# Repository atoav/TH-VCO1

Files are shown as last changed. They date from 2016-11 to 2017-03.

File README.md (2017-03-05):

# TH-VCO1

This is a fork based on [the Eurorack Layout Tom Whitwell]( http://www.birthofasynth.com/Thomas_Henry/Pages/VCO-1.html) Oscillator published for the [Thomas Henry VCO 1](http://www.birthofasynth.com/Thomas_Henry/Pages/VCO-1.html) Oscillator.

**NB: All rights to this design rest with Thomas Henry. I do not claim or grant any copyright or license to this design. This is the outcome of an University course at HFBK Hamburg. A limited run of 100 pieces has been produced, which will be sold. We are not allowed to share CAD files of the circuit as "Thomas Henry prefers that all hardware for my designs come from Fonik only, and that schematics for his designs come from Scott and E-M". I will take this page down if he asks me to.** 

## Changes
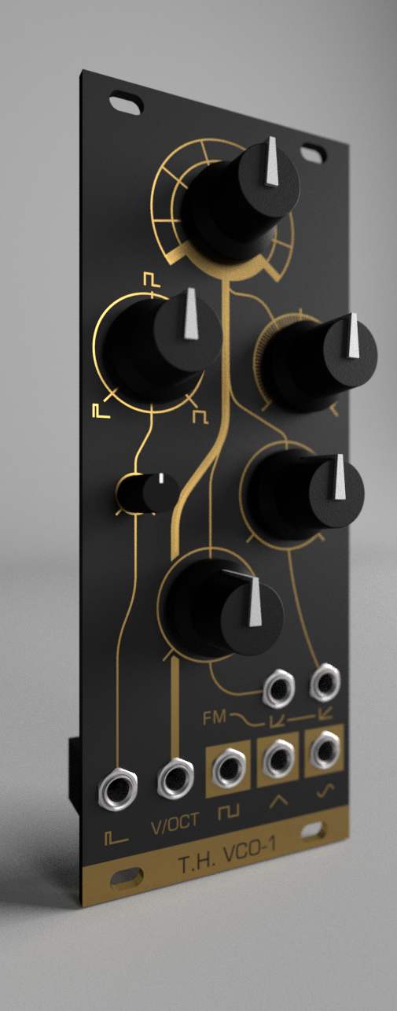
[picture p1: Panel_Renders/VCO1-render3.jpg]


Compared to Tom's Layout some things changed:

- the complete panel layout has been changed for a fancier (and imho a bit more easier to grasp) layout
- The board-pot has been completely rerouted and is now a single layer board (the bottom layer is a nice, undivided ground plane)
- Two 1x5 Header Pin Strips have been added (this could potentially help to save the screws and add mechanical stability)
- All Resistor Pads have been swapped for square pads
- The PWM CV Attenuator Pot is now a 9mm Alpha trimmer (the small ones with the plastic head, commonly used for attenuverters)
- Cleaned up traces and silkscreen where necessary

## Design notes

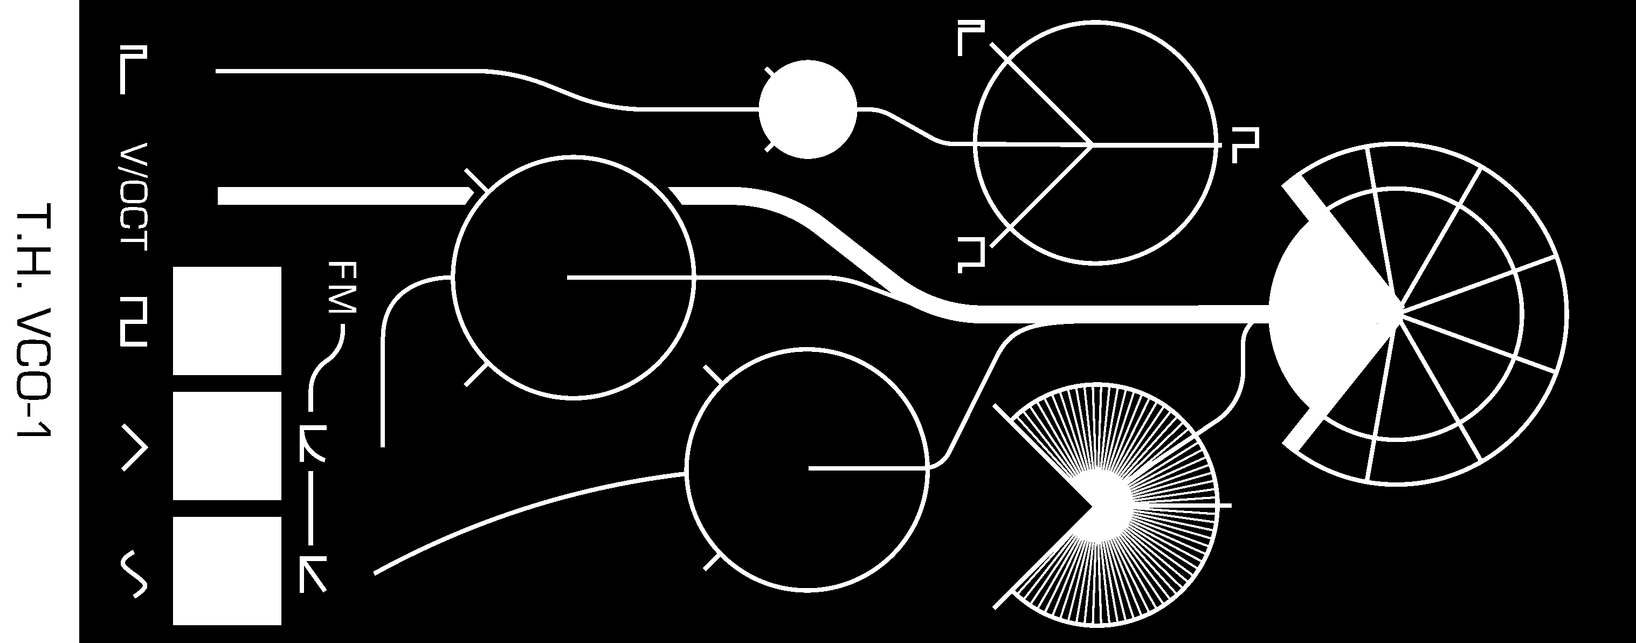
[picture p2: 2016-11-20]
Panel_Images/VCO1-Panel_Board-01.bmp

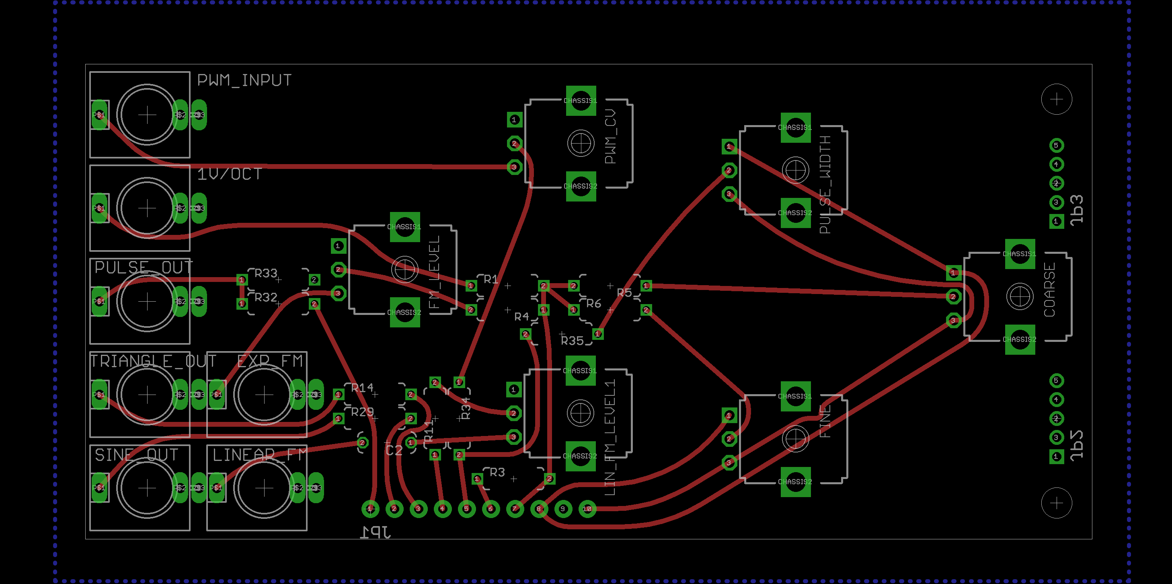
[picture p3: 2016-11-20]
Board_Images/vco1-board-pots.png

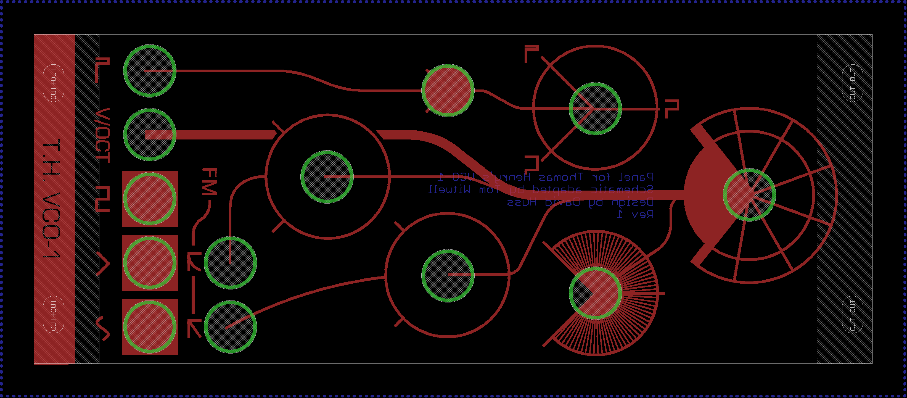
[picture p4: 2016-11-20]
Board_Images/vco1-board-panel.png

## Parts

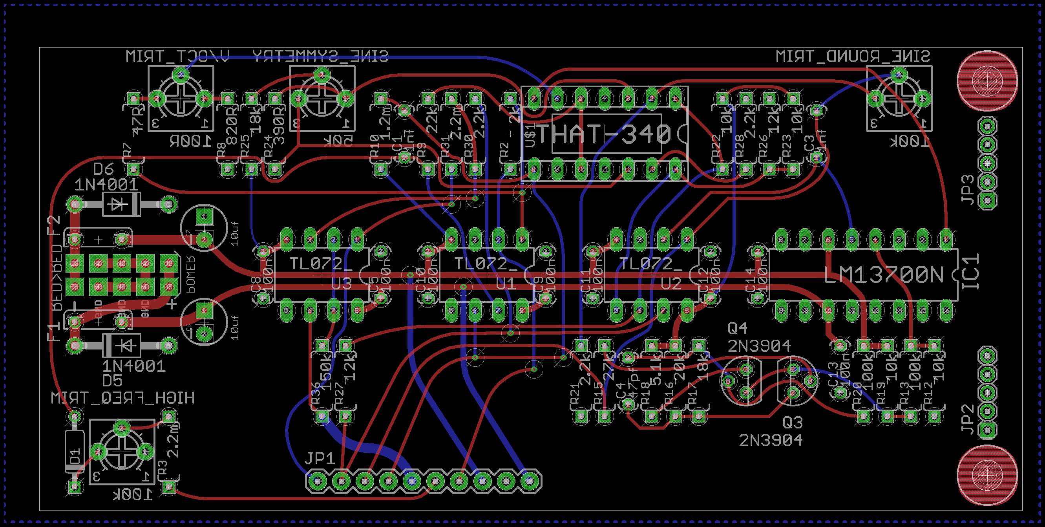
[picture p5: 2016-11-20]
Board_Images/vco1-board-components.jpg

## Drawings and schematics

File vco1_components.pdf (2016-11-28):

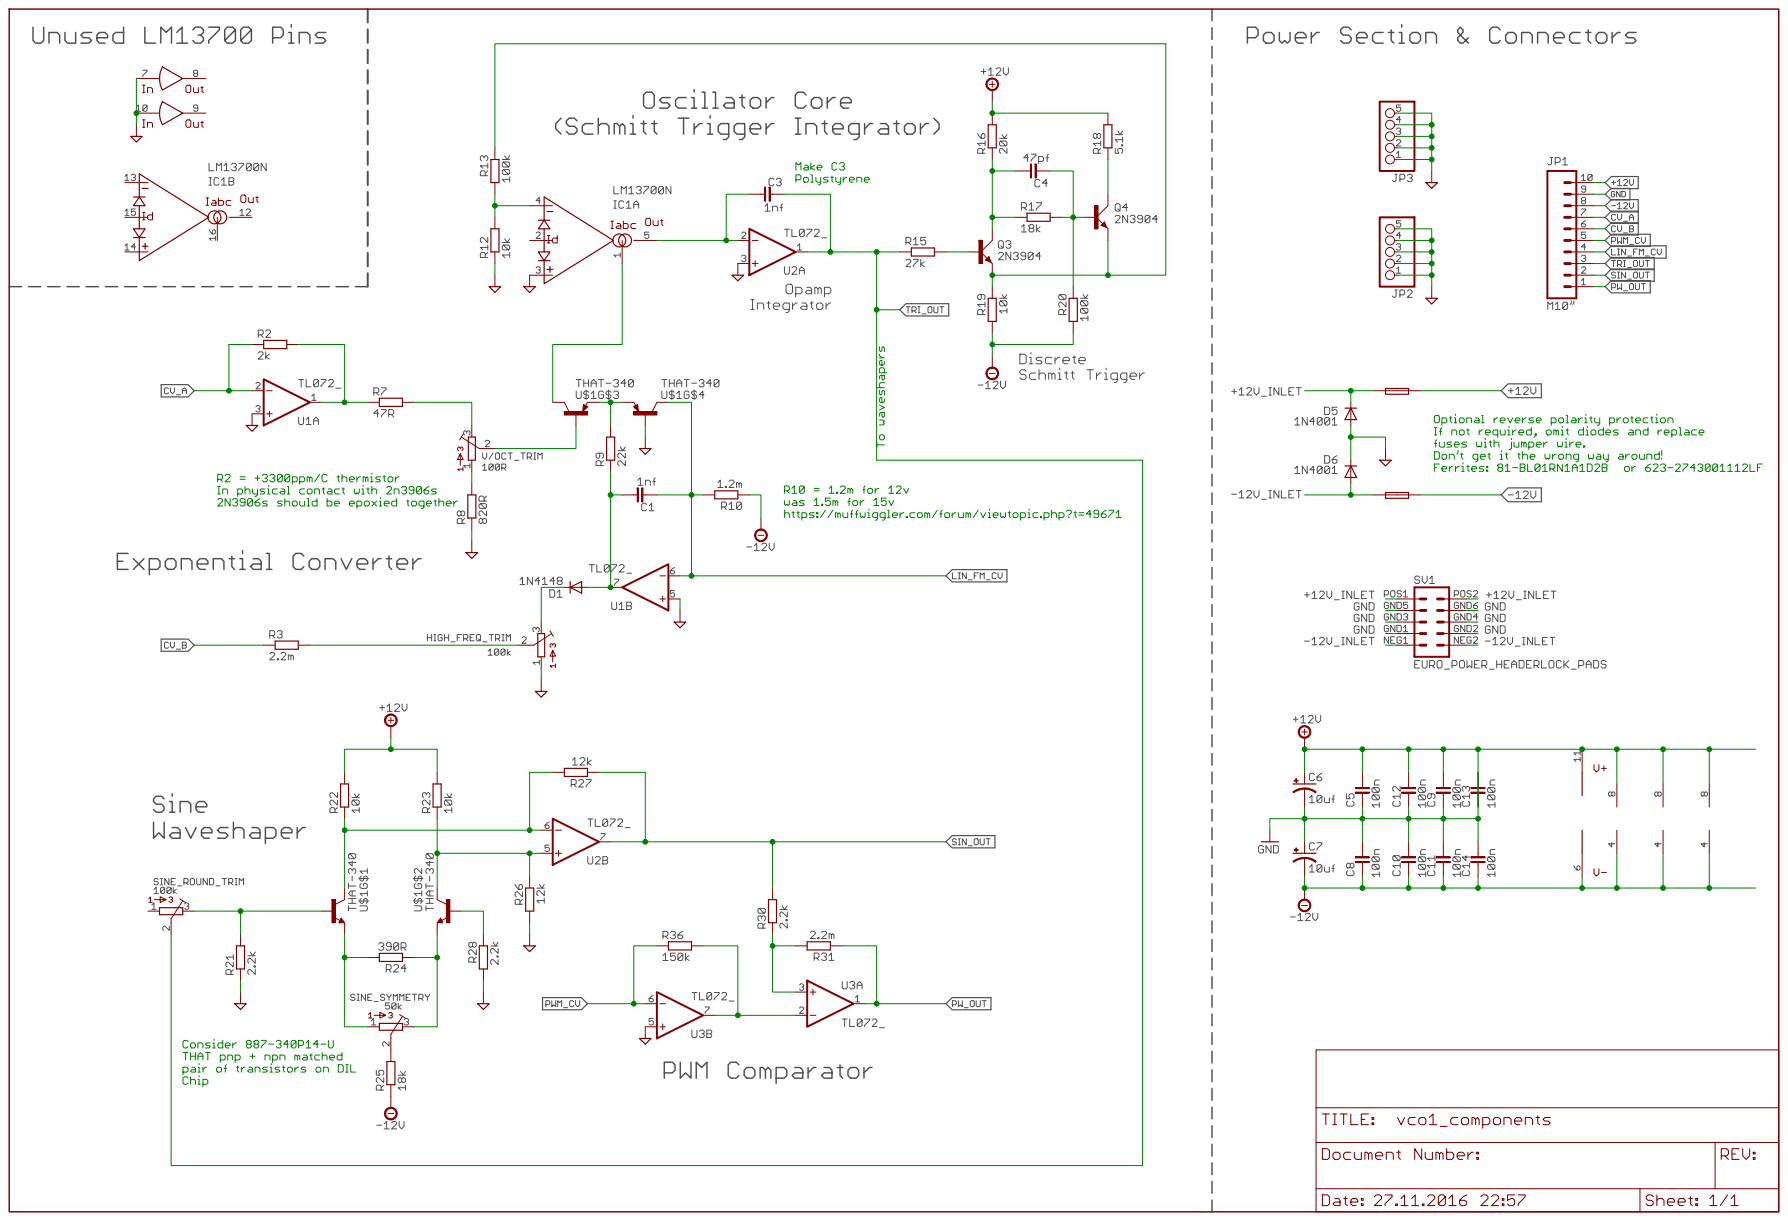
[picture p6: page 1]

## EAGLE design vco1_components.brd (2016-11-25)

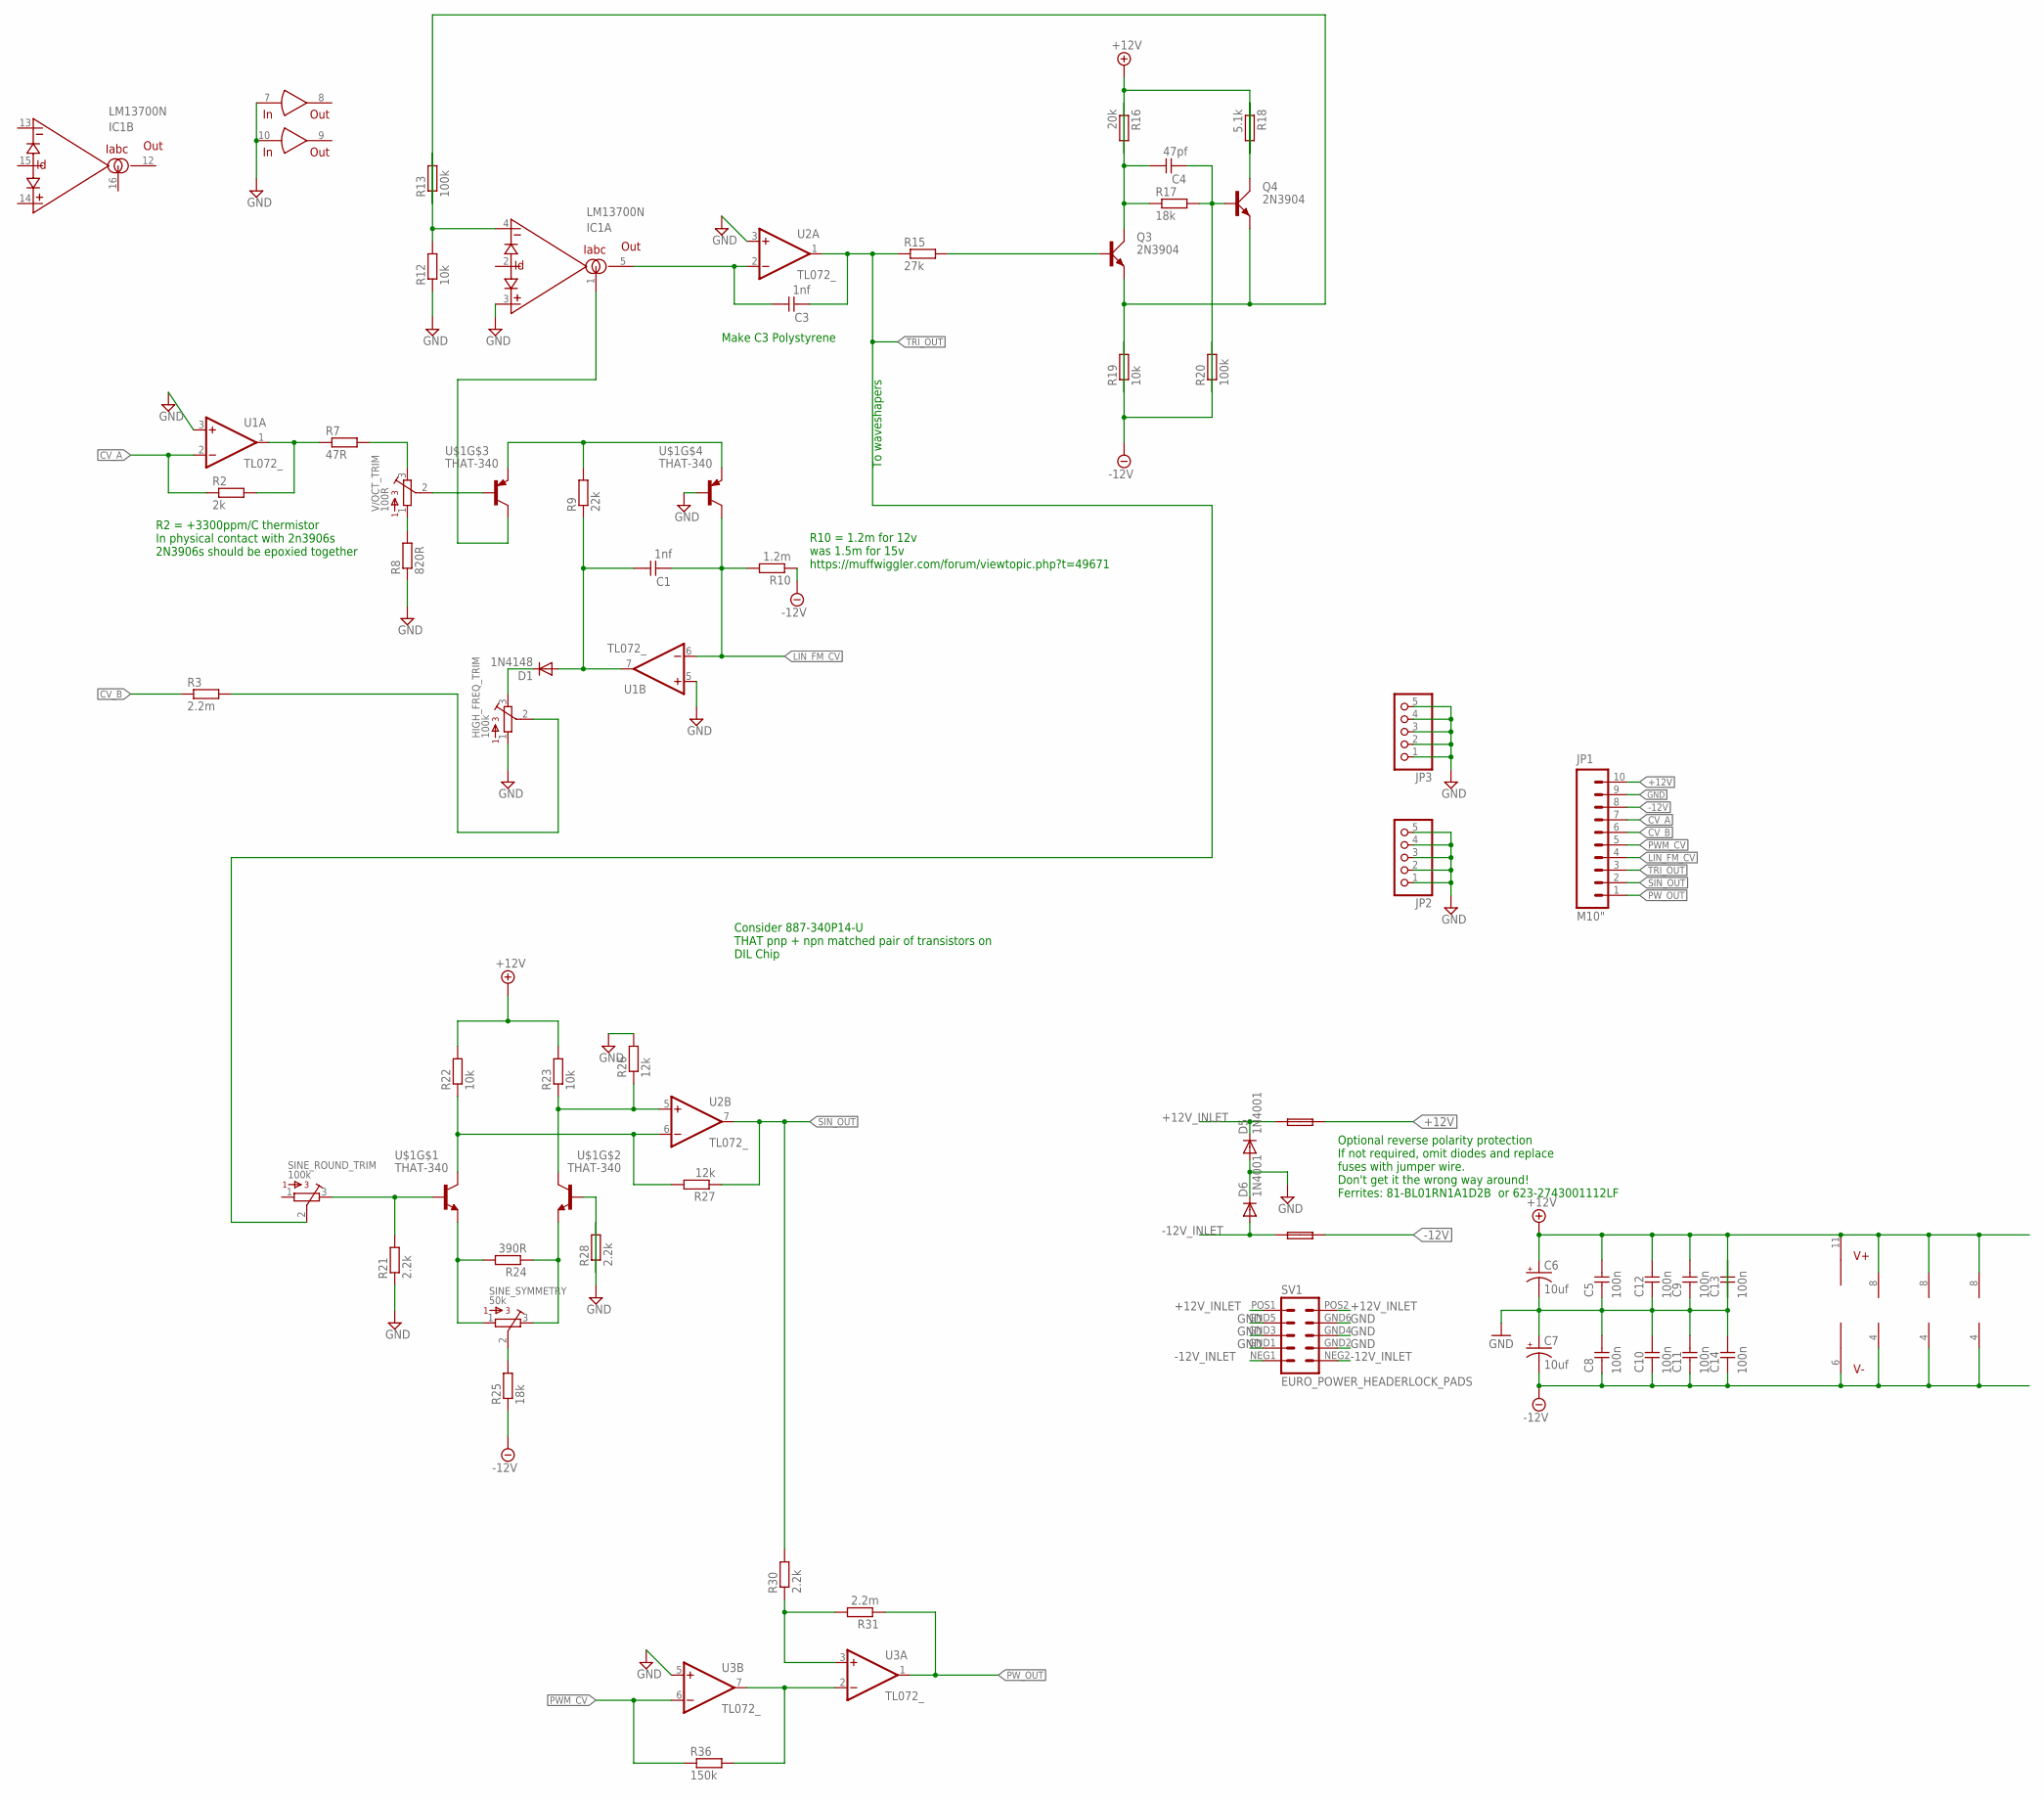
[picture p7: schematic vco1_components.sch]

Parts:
C1, C3: 1nf; C050-024X044
C4: 47pf; C050-024X044
C5, C8, C9, C10, C11, C12, C13, C14: 100n; C050-024X044
C6, C7: 10uf; CPOL-RADIAL-10UF-25V
D1: 1N4148; DO35-7
D5, D6: 1N4001; DO41-10
F1, F2: FUSE; C050H075X075
HIGH_FREQ_TRIM: 100k; BOURNS_3362P_TRIMMER
IC1: LM13700N; DIL16
JP1: M10"; 1X10
JP2, JP3: PINHD-1X55X2MM; 1_05X2MM
Q3, Q4: 2N3904; TO92D
R2: 2k; 7MM_RESISTOR
R3, R31: 2.2m; 7MM_RESISTOR
R7: 47R; 7MM_RESISTOR
R8: 820R; 7MM_RESISTOR
R9: 22k; 7MM_RESISTOR
R10: 1.2m; 7MM_RESISTOR
R12, R19, R22, R23: 10k; 7MM_RESISTOR
R13, R20: 100k; 7MM_RESISTOR
R15: 27k; 7MM_RESISTOR
R16: 20k; 7MM_RESISTOR
R17, R25: 18k; 7MM_RESISTOR
R18: 5.1k; 7MM_RESISTOR
R21, R28, R30: 2.2k; 7MM_RESISTOR
R24: 390R; 7MM_RESISTOR
R26, R27: 12k; 7MM_RESISTOR
R36: 150k; 7MM_RESISTOR
SINE_ROUND_TRIM: 100k; BOURNS_3362P_TRIMMER
SINE_SYMMETRY: 50k; BOURNS_3362P_TRIMMER
SV1: EURO_POWER_HEADERLOCK_PADS; EURO_PWR_HEADER_LOCK
U1, U2, U3: TL072_; DIL08
U$1: THAT-340; DIL14
V/OCT_TRIM: 100R; BOURNS_3362P_TRIMMER

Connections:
+12V: C5.1, C6.1 (+), C9.1, C12.1, C13.2, F1.2, IC1.11 (V+), JP1.10, R16.2, R18.2, R22.2, R23.2, U1.8 (V+), U2.8 (V+), U3.8 (V+)
+12V_INLET: D5.C, F1.1, SV1.POS1 (10), SV1.POS2 (9)
-12V: C7.2 (-), C8.2, C10.2, C11.2, C14.2, F2.2, IC1.6 (V-), JP1.8, R10.1, R19.2, R20.2, R25.1, U1.4 (V-), U2.4 (V-), U3.4 (V-)
-12V_INLET: D6.A, F2.1, SV1.NEG1 (2), SV1.NEG2 (1)
CV_A: JP1.7, R2.1, U1.2 (-IN)
CV_B: JP1.6, R3.1
GND: C5.2, C6.2 (-), C7.1 (+), C8.1, C9.2, C10.1, C11.1, C12.2, C13.1, C14.1, D5.A, D6.C, HIGH_FREQ_TRIM.1, IC1.3 (+IN), IC1.7 (IN), IC1.10 (IN), JP1.9, JP2.1, JP2.2, JP2.3, JP2.4, JP2.5, JP3.1, JP3.2, JP3.3, JP3.4, JP3.5, R8.1, R12.1, R21.1, R26.2, R28.2, SV1.GND1 (4), SV1.GND2 (3), SV1.GND3 (6), SV1.GND4 (5), SV1.GND5 (8), SV1.GND6 (7), U1.3 (+IN), U1.5 (+IN), U2.3 (+IN), U3.5 (+IN), U$1.9 (B)
LIN_FM_CV: C1.2, JP1.4, R10.2, U1.6 (-IN), U$1.8 (C)
unnamed: R2.2, R7.1, U1.1 (OUT)
unnamed: R7.2, V/OCT_TRIM.3
unnamed: R8.2, V/OCT_TRIM.1
unnamed: U$1.6 (B), V/OCT_TRIM.2
unnamed: R9.2, U$1.5 (E), U$1.10 (E)
unnamed: IC1.1 (IABC), U$1.7 (C)
unnamed: C1.1, D1.A, R9.1, U1.7 (OUT)
unnamed: D1.C, HIGH_FREQ_TRIM.3
unnamed: HIGH_FREQ_TRIM.2, R3.2
unnamed: IC1.4 (-IN), R12.2, R13.2
unnamed: C3.1, IC1.5 (OUT), U2.2 (-IN)
unnamed: Q3.B, R15.2
unnamed: C4.1, Q3.C, R16.1, R17.1
unnamed: R21.2, SINE_ROUND_TRIM.3, U$1.2 (B)
unnamed: C4.2, Q4.B, R17.2, R20.1
unnamed: Q4.C, R18.1
unnamed: R25.2, SINE_SYMMETRY.2
unnamed: Q3.E, Q4.E, R13.1, R19.1
unnamed: R22.1, R27.2, U2.6 (-IN), U$1.1 (C)
unnamed: R23.1, R26.1, U2.5 (+IN), U$1.14 (C)
unnamed: R24.2, SINE_SYMMETRY.1, U$1.3 (E)
unnamed: R24.1, SINE_SYMMETRY.3, U$1.12 (E)
unnamed: R28.1, U$1.13 (B)
unnamed: R30.1, R31.2, U3.3 (+IN)
unnamed: R36.2, U3.2 (-IN), U3.7 (OUT)
PWM_CV: JP1.5, R36.1, U3.6 (-IN)
PW_OUT: JP1.1, R31.1, U3.1 (OUT)
SIN_OUT: JP1.2, R27.1, R30.2, U2.7 (OUT)
TRI_OUT: C3.2, JP1.3, R15.1, SINE_ROUND_TRIM.2, U2.1 (OUT)

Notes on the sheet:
To waveshapers
R2 = +3300ppm/C thermistor In physical contact with 2n3906s 2N3906s should be epoxied together
Make C3 Polystyrene
R10 = 1.2m for 12v was 1.5m for 15v https://muffwiggler.com/forum/viewtopic.php?t=49671
Consider 887-340P14-U THAT pnp + npn matched pair of transistors on DIL Chip
Optional reverse polarity protection If not required, omit diodes and replace fuses with jumper wire. Don't get it the wrong way around! Ferrites: 81-BL01RN1A1D2B or 623-2743001112LF

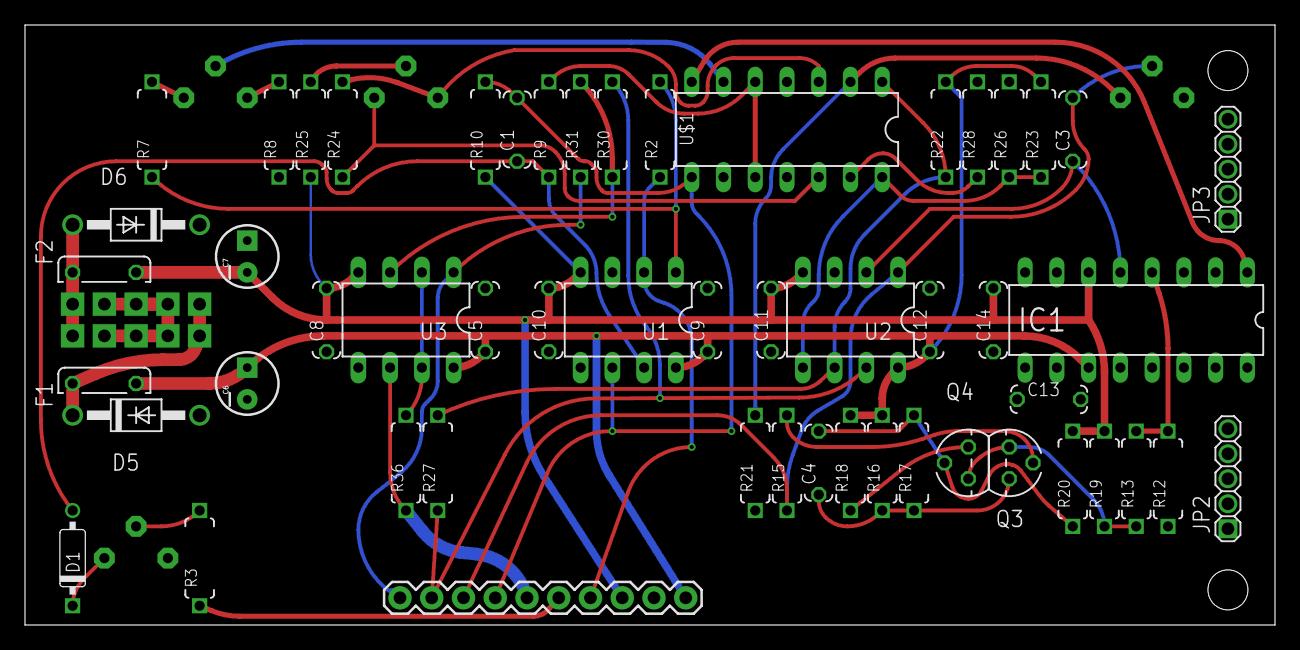
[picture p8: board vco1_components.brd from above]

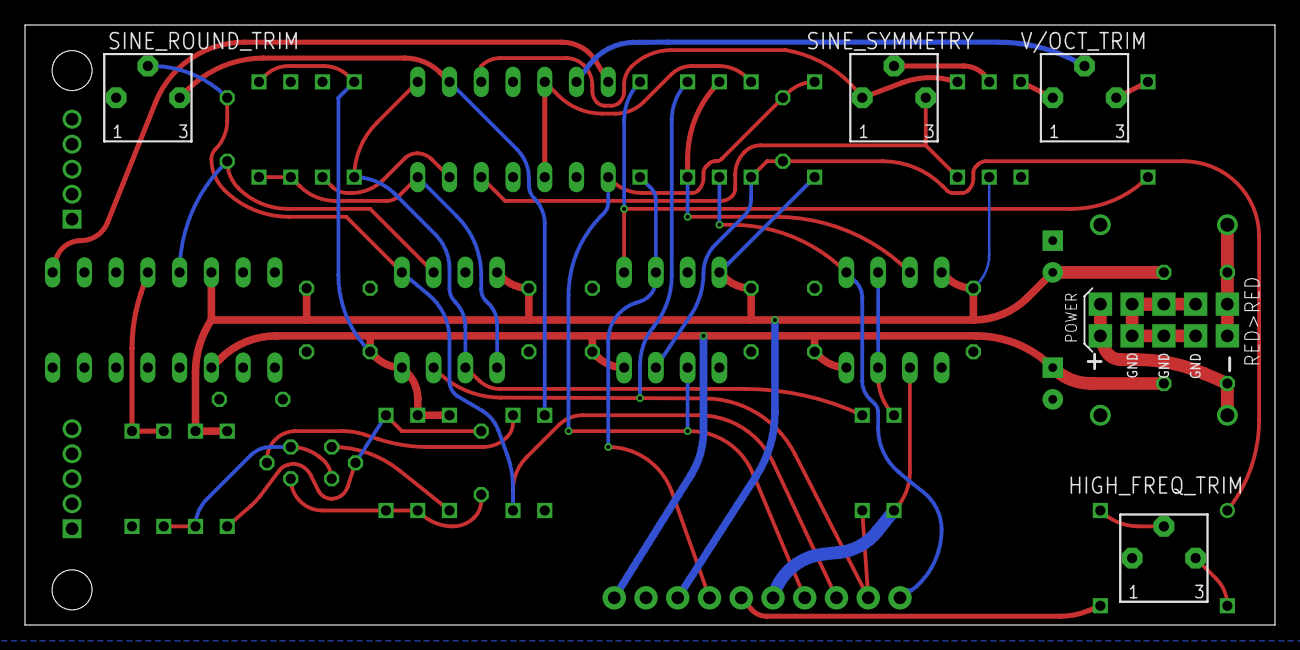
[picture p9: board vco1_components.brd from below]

Board: 2 copper layers, 100.0 x 48.0 mm, 58 parts (5 on the bottom side), 37 nets.

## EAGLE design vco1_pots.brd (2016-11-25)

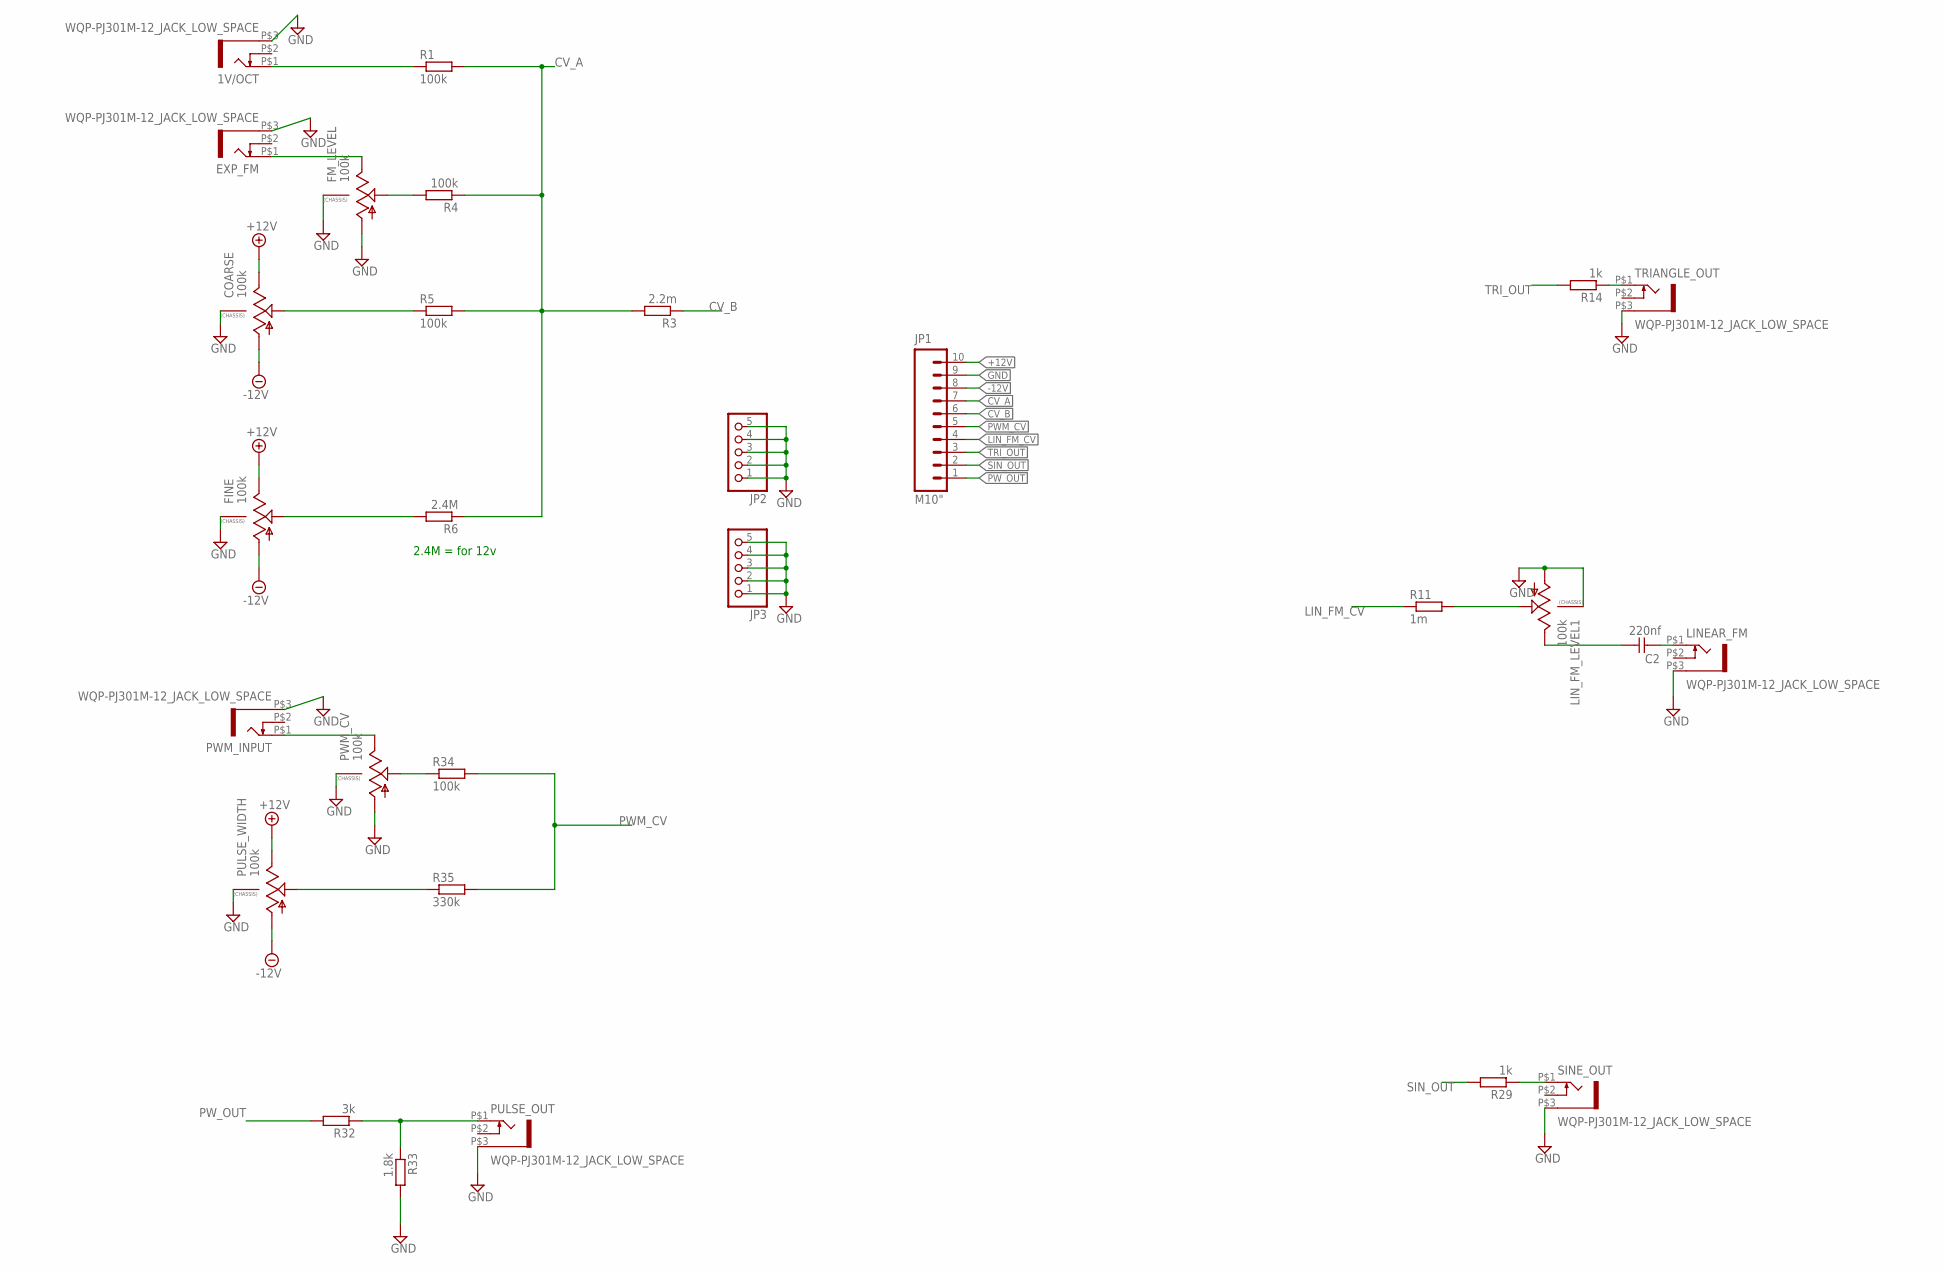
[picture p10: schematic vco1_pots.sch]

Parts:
1V/OCT: WQP-PJ301M-12_JACK_LOW_SPACE
C2: 220nf; C050-024X044
COARSE: 100k; 9MM_SNAP-IN_POT
EXP_FM: WQP-PJ301M-12_JACK_LOW_SPACE
FINE: 100k; 9MM_SNAP-IN_POT
FM_LEVEL: 100k; 9MM_SNAP-IN_POT
JP1: M10"; 1X10
JP2, JP3: PINHD-1X55X2MM; 1_05X2MM
LINEAR_FM: WQP-PJ301M-12_JACK_LOW_SPACE
LIN_FM_LEVEL1: 100k; 9MM_SNAP-IN_POT
PULSE_OUT: WQP-PJ301M-12_JACK_LOW_SPACE
PULSE_WIDTH: 100k; 9MM_SNAP-IN_POT
PWM_CV: 100k; 9MM_SNAP-IN_POT
PWM_INPUT: WQP-PJ301M-12_JACK_LOW_SPACE
R1, R4, R5, R34: 100k; 7MM_RESISTOR
R3: 2.2m; 7MM_RESISTOR
R6: 2.4M; 7MM_RESISTOR
R11: 1m; 7MM_RESISTOR
R14, R29: 1k; 7MM_RESISTOR
R32: 3k; 7MM_RESISTOR
R33: 1.8k; 7MM_RESISTOR
R35: 330k; 7MM_RESISTOR
SINE_OUT: WQP-PJ301M-12_JACK_LOW_SPACE
TRIANGLE_OUT: WQP-PJ301M-12_JACK_LOW_SPACE

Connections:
+12V: COARSE.3 (E), FINE.3 (E), JP1.10, PULSE_WIDTH.3 (E)
-12V: COARSE.1 (A), FINE.1 (A), JP1.8, PULSE_WIDTH.1 (A)
CV_A: JP1.7, R1.2, R3.2, R4.1, R5.2, R6.1
CV_B: JP1.6, R3.1
GND: 1V/OCT.P$3 (1), COARSE.CHASSIS2, EXP_FM.P$3 (1), FINE.CHASSIS2, FM_LEVEL.1 (A), FM_LEVEL.CHASSIS2, JP1.9, JP2.1, JP2.2, JP2.3, JP2.4, JP2.5, JP3.1, JP3.2, JP3.3, JP3.4, JP3.5, LINEAR_FM.P$3 (1), LIN_FM_LEVEL1.1 (A), LIN_FM_LEVEL1.CHASSIS2, PULSE_OUT.P$3 (1), PULSE_WIDTH.CHASSIS2, PWM_CV.1 (A), PWM_CV.CHASSIS2, PWM_INPUT.P$3 (1), R33.2, SINE_OUT.P$3 (1), TRIANGLE_OUT.P$3 (1)
LIN_FM_CV: JP1.4, R11.1
unnamed: 1V/OCT.P$1 (2), R1.1
unnamed: EXP_FM.P$1 (2), FM_LEVEL.3 (E)
unnamed: FM_LEVEL.2 (S), R4.2
unnamed: COARSE.2 (S), R5.1
unnamed: FINE.2 (S), R6.2
unnamed: LIN_FM_LEVEL1.2 (S), R11.2
unnamed: R14.1, TRIANGLE_OUT.P$1 (2)
unnamed: C2.1, LIN_FM_LEVEL1.3 (E)
unnamed: C2.2, LINEAR_FM.P$1 (2)
unnamed: R29.1, SINE_OUT.P$1 (2)
unnamed: PULSE_OUT.P$1 (2), R32.1, R33.1
unnamed: PWM_CV.3 (E), PWM_INPUT.P$1 (2)
unnamed: PWM_CV.2 (S), R34.1
unnamed: PULSE_WIDTH.2 (S), R35.1
PWM_CV: JP1.5, R34.2, R35.2
PW_OUT: JP1.1, R32.2
SIN_OUT: JP1.2, R29.2
TRI_OUT: JP1.3, R14.2

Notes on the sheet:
2.4M = for 12v

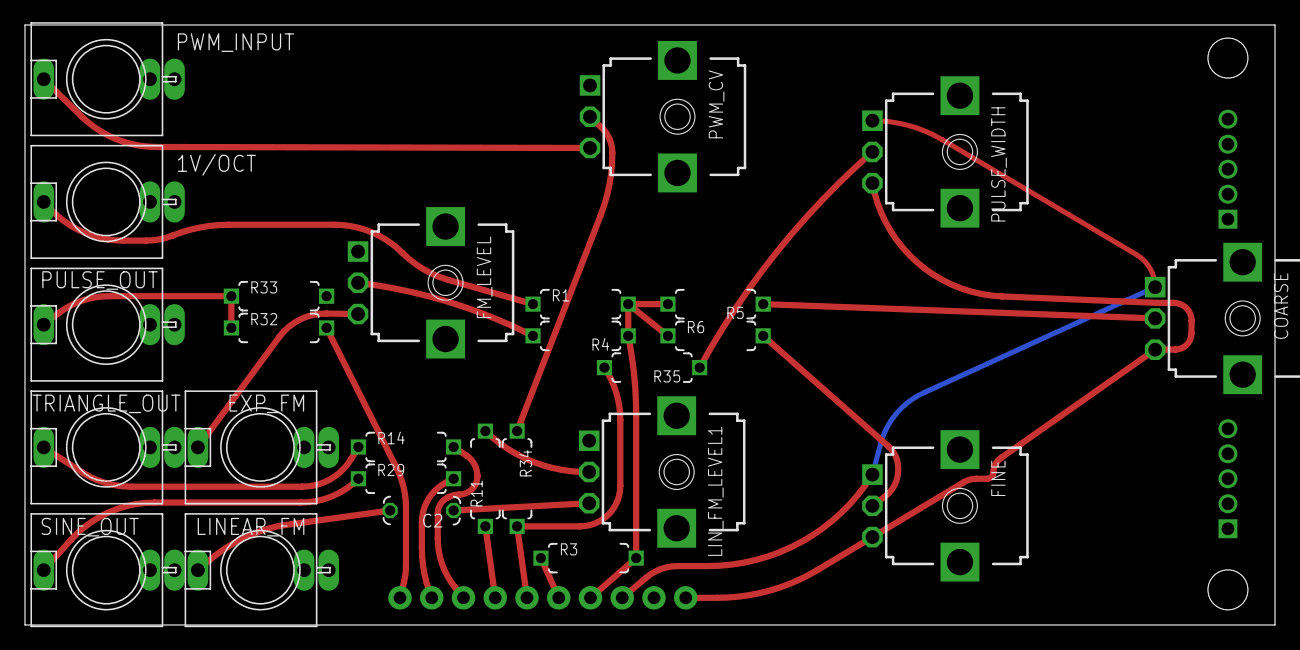
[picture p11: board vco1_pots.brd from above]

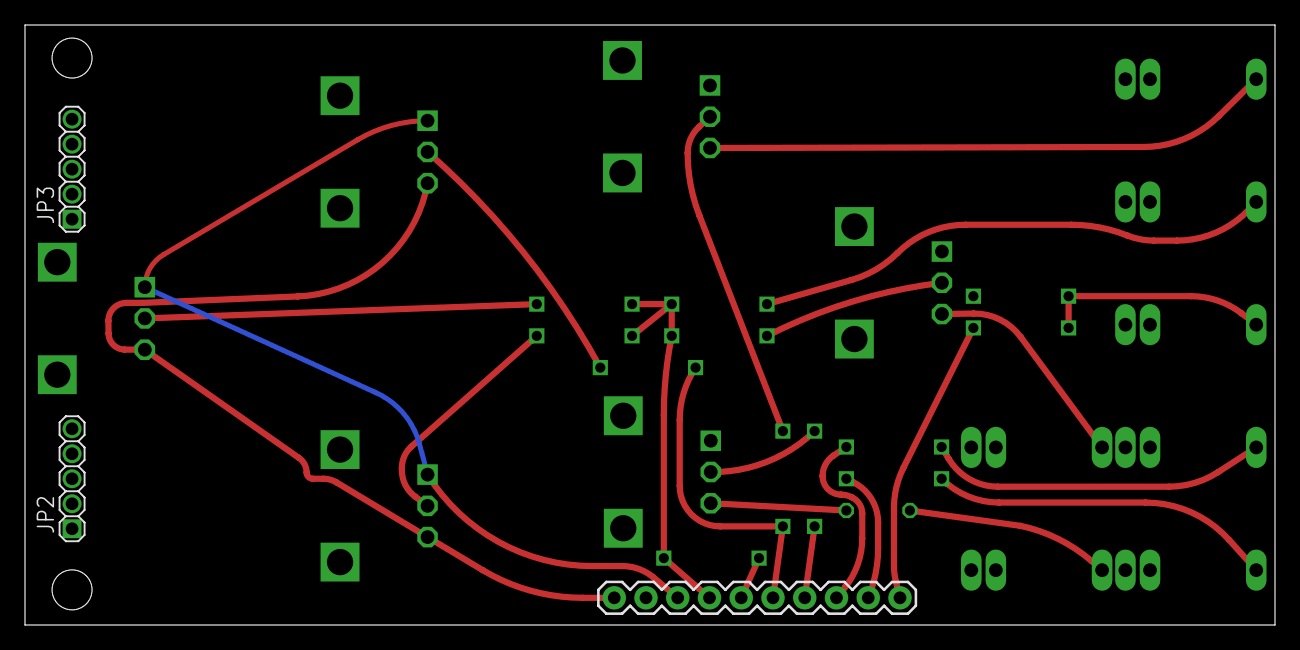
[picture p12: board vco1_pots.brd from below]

Board: 2 copper layers, 100.0 x 48.0 mm, 31 parts (3 on the bottom side), 24 nets.

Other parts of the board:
U$2, U$3: MOUNTING_HOLE

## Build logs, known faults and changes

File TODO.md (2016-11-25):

# TODO

- [ ] **Panel:** import inverted bitmap traces to tStop
- [ ] **Panel:** replace Vias with Holes  → max. Standard drill size Ø 6.3mm, measure
- [ ] **Panel:** move text from bottom silk to bottom copper

http://www.elecrow.com/

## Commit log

2016-11-20 Massive Changes, See Readme
    [vco1_components.brd, vco1_components.sch, vco1_panel.brd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]
2016-11-25 Changed PCB Size, Moved Frequency Knob
    Adapted PCB Boards for the (cheaper) size of 100x49mm which allows two
    PCBs on one 100x100mm Panel. Frequency Pot had to be moved X -1mm
    [vco1_components.brd, vco1_pots.brd]
2016-11-25 Fixed small Clearance Problems
    [vco1_components.brd, vco1_pots.brd]
2016-11-28 Cleanup of the Board schematics
    [vco1_components.sch]

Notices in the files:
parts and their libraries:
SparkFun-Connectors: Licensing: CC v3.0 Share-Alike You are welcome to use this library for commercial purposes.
